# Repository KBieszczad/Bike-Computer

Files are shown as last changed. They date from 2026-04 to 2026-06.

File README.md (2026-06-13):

# Custom IoT Bike Computer

A low-power custom bicycle computer featuring speed measurement, GPS tracking, environmental sensing, and an OLED display. The hardware is designed from scratch with a custom PCB created in KiCad.

## Description

This project aims to build a standalone, power-efficient bike computer. At its core is the Seeed Studio **XIAO nRF52840**, a very energy efficient microcontroller with native Bluetooth Low Energy support.

The device combines data from a classic magnetic reed switch (for precise speed and distance tracking) with an external GPS module for recording traces. Additionally, it integrates a BME280 sensor to monitor environmental conditions (temperature, humidity, and barometric pressure).

### Technical Features
* **Super-Loop Architecture:** Runs on a non-blocking state machine utilizing hardware interrupts (ISR) and atomics for exact speed calculation and UI rendering, completely avoiding `delay()` functions.
* **Persistent Storage (LittleFS):** Automatically saves user settings, wheel circumference, and route history to the internal non-volatile flash memory.
* **GPS Trace Recording:** Caches GPS coordinates in the background while moving and writes directly to flash. Traces can be directly exported over USB Serial to a raw `.gpx` file compatible with for example Strava.
* **Dynamic Power Management:** Implements multiple power modes (Normal, Eco, Ultra Eco). The device sends standard CASIC protocol sleep commands to the GPS module and hardware sleep flags to the BME280 sensor to drastically cut power consumption when full tracking is not needed.

## Hardware Components

* **MCU:** Seeed Studio XIAO nRF52840
* **GPS Module:** ATGM336H
* **Environment Sensor:** BME280
* **Display:** 1.54" I2C OLED (SSD1309)
* **Sensors:** Magnetic Reed Switch (Normally Open)
* **Power:** 470mAh Li-Pol Battery with hardware switch

## Project Structure

```text
.
├── hardware/
│   ├── project.kicad_sch        # KiCad Schematic file
│   ├── project.kicad_pcb        # KiCad PCB layout file
│   └── img/                     # Schematic and PCB layout images
├── software/                    # PlatformIO Firmware files
└── README.md
```

## Visuals

### Schematic
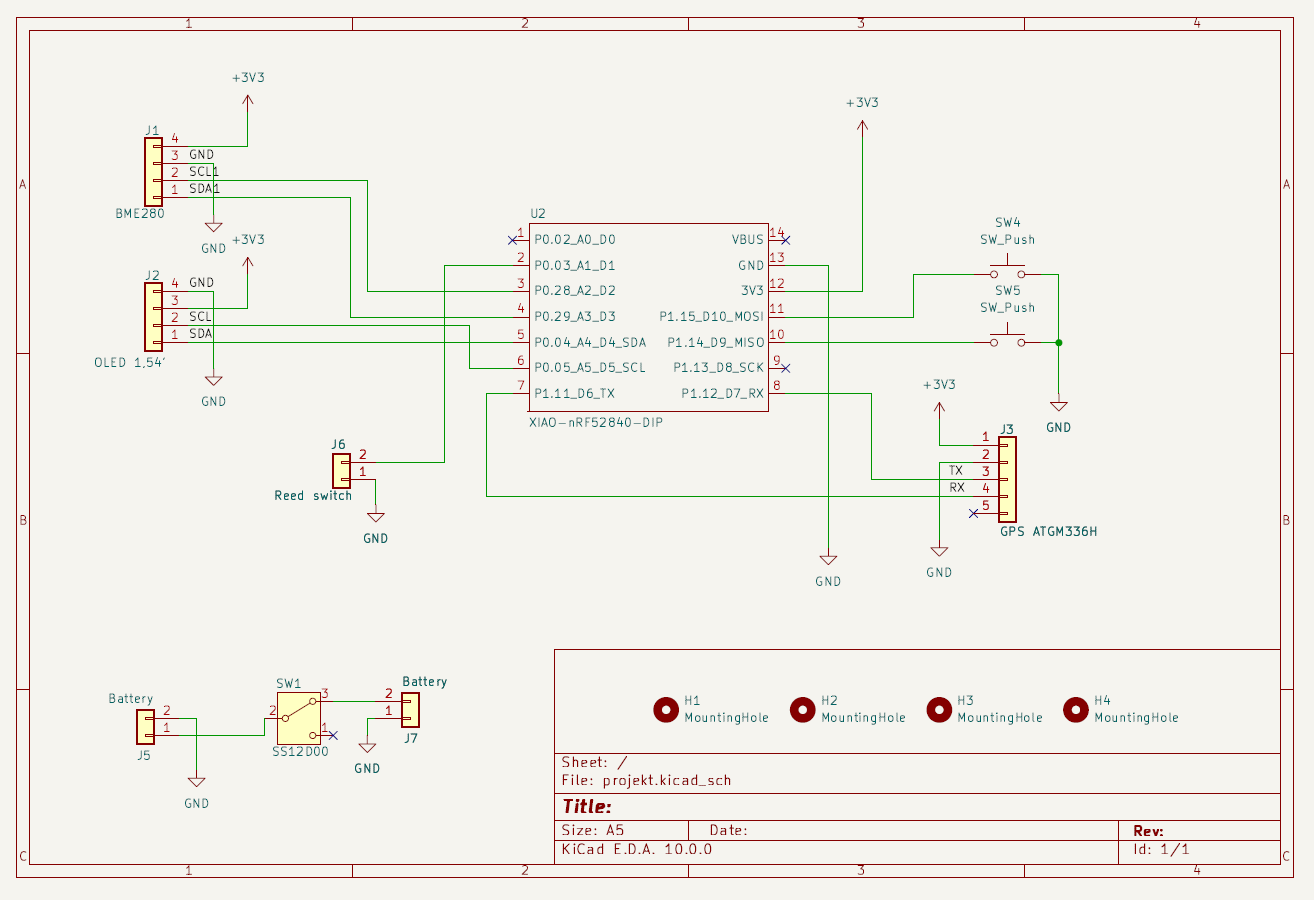
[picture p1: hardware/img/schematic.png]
Schematics


### PCB
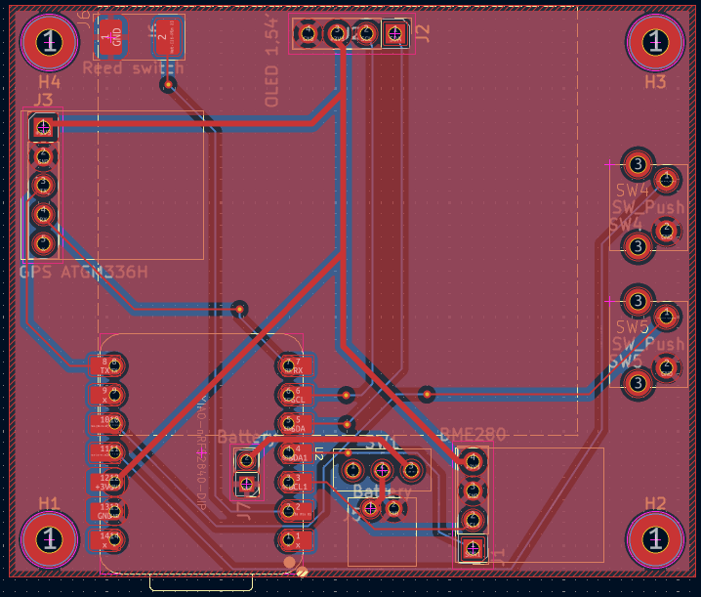
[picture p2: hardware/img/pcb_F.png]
Front

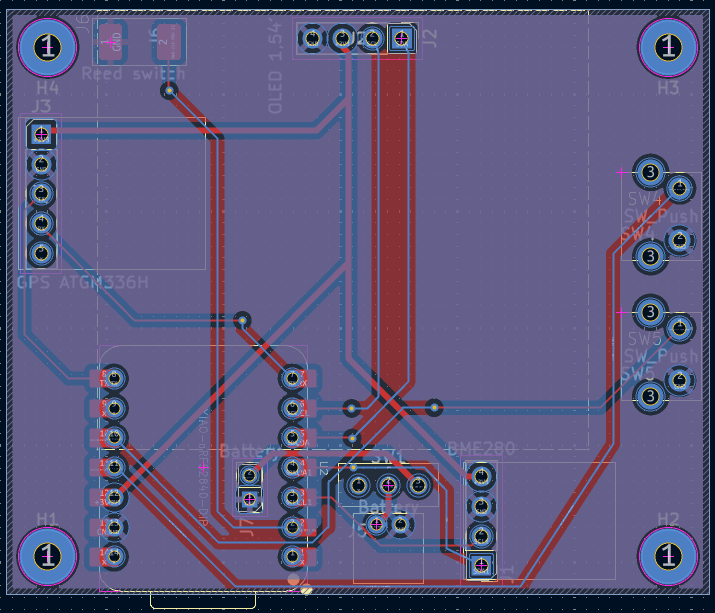
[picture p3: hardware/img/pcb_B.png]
Back


## Installation & Build

### Prerequisites
* **Visual Studio Code** with the **PlatformIO** extension installed.
* Required libraries are automatically managed by `platformio.ini`

### Installing & Flashing
1. **Clone the repository:**
```bash
git clone https://github.com/KBieszczad/Bike-Computer.git
```
2. **Open the `software` folder** in VS Code (PlatformIO).
3. **Connect your XIAO nRF52840** via USB-C.
4. **Build and Upload** the firmware using the PlatformIO build tools.

## Usage & Configuration

1. **Navigation:**
   * **Button 1 (Left):** Short press to cycle through the available screens (Main, Environment, History, GPS, Wheel Setup, Power Mode).
   * **Button 2 (Right):** Used to interact with the current screen (e.g., scroll menus, change settings).
2. **Recording a Trip:**
   * Ensure GPS is toggled `ON` in the GPS Settings screen. The device will automatically start tracking your route once satellites are locked and movement is detected.
   * To finish and save the trip into the device's history, navigate to the **Main Screen**, press and hold **Button 2** for 2 seconds. The trip history will update and distance will reset.
3. **Exporting GPX Track:**
   * Connect the bike computer to a PC via USB.
   * Open a Serial Monitor tool (e.g., in PlatformIO) set to `115200` baud.
   * Navigate to the **GPS SETTINGS** screen on the device, select **EXPORT ROUTE**, and hold Button 2.
   * The device will output raw XML data. Copy this text, save it as a `.gpx` file, and upload it directly to Strava or GPX Studio.

## Authors
Krzysztof Bieszczad
[@KBieszczad](https://github.com/KBieszczad)

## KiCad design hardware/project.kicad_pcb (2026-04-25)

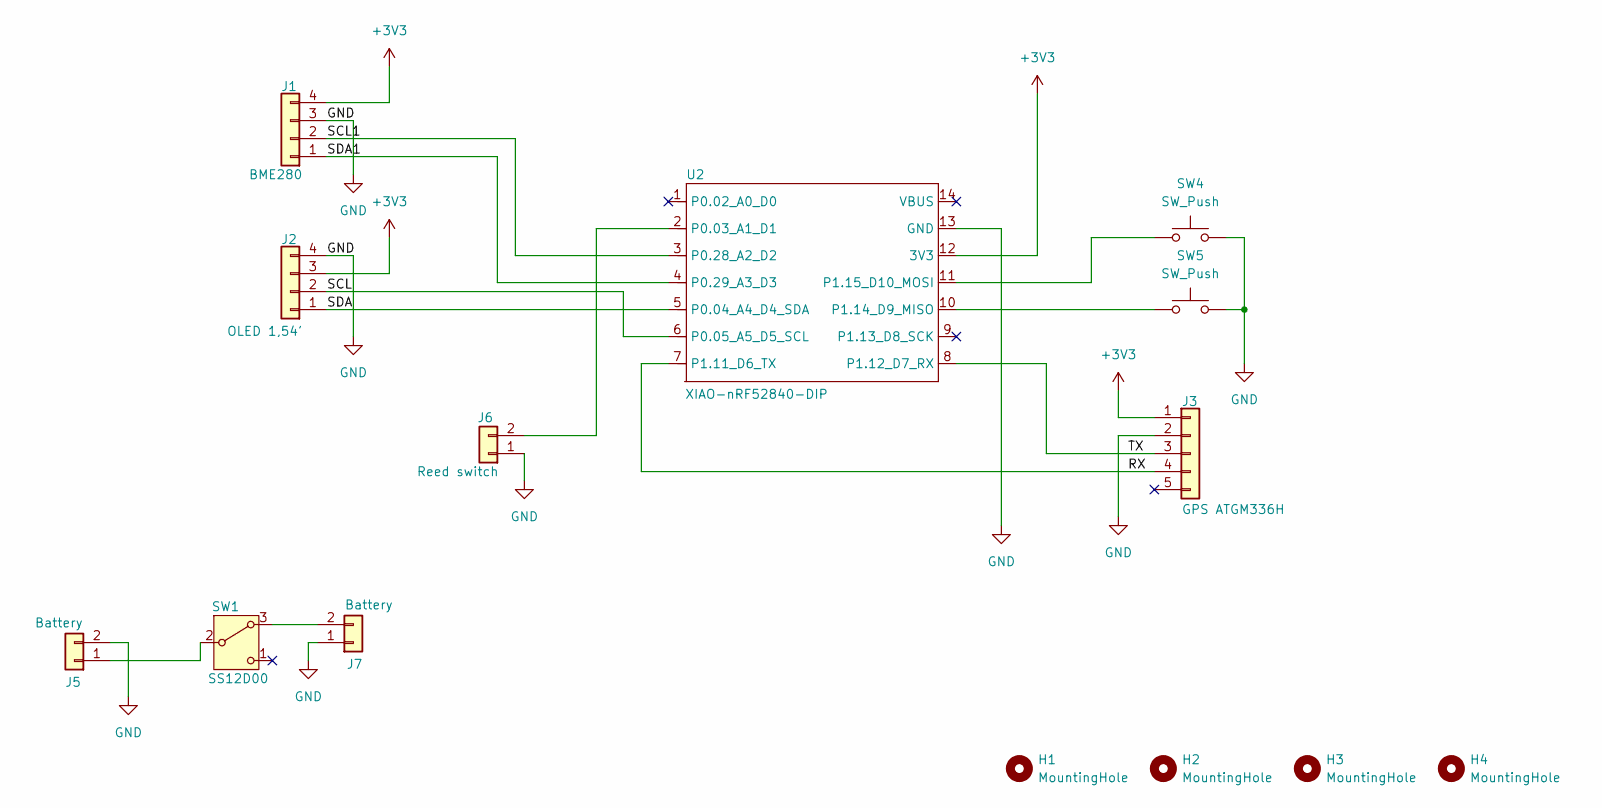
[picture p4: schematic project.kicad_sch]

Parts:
H1, H2, H3, H4: MountingHole; MountingHole_2.2mm_M2_Pad
J1: BME280; PinHeader_1x04_P2.54mm_Vertical
J2: OLED 1,54'; PinHeader_1x04_P2.54mm_Vertical
J3: GPS ATGM336H; PinHeader_1x05_P2.54mm_Vertical
J5: Battery; jst_2mm
J6: Reed switch; reed_switch
J7: Battery; PinHeader_1x02_P2.00mm_Vertical
SW1: SS12D00
SW4, SW5: SW_Push; tact_switch
U2: XIAO-nRF52840-DIP

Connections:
+3V3: J1.4, J2.3, J3.1, U2.12 (3V3)
/RX: J3.4, U2.7 (P1.11_D6_TX)
/SCL: J2.2, U2.6 (P0.05_A5_D5_SCL)
/SCL1: J1.2, U2.3 (P0.28_A2_D2)
/SDA: J2.1, U2.5 (P0.04_A4_D4_SDA)
/SDA1: J1.1, U2.4 (P0.29_A3_D3)
/TX: J3.3, U2.8 (P1.12_D7_RX)
GND: J1.3, J2.4, J3.2, J5.2, J6.1, J7.1, SW4.2, SW5.2, U2.13 (GND)
unnamed: J5.1, SW1.2 (B)
unnamed: J6.2, U2.2 (P0.03_A1_D1)
unnamed: J7.2, SW1.3 (A)
unnamed: SW5.1, U2.10 (P1.14_D9_MISO)
unnamed: SW4.1, U2.11 (P1.15_D10_MOSI)

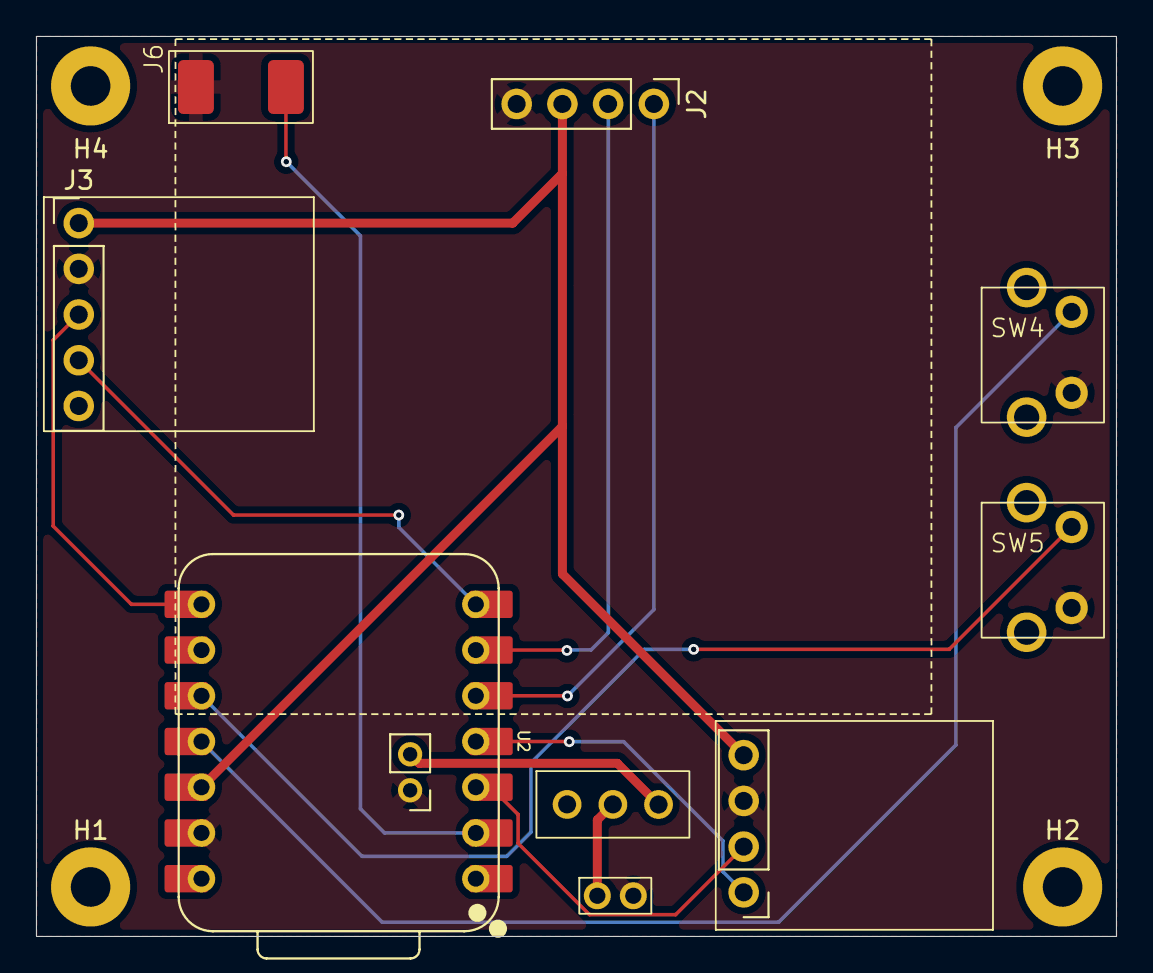
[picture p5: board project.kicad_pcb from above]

Board: 2 copper layers, 60.0 x 50.0 mm, 14 parts (0 on the bottom side), 13 nets.

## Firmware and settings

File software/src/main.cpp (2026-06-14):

#include <Arduino.h>
#include <U8g2lib.h>
#include <Wire.h>
#include <Adafruit_Sensor.h>
#include <Adafruit_BME280.h>
#include <TinyGPSPlus.h>
#include <Bounce2.h>
#include "Globals.h"
#include "Bitmaps.h"

SystemSettings settings = {2155, MODE_NORMAL, true, 0};
Screen currentScreen = SCREEN_MAIN;

volatile float speedKmh = 0.0;
volatile float distanceTripKm = 0.0;
volatile uint32_t tripDurationSec = 0;
float temp = 0.0, hum = 0.0, pres = 0.0;
uint8_t batteryPercent = 100;
bool gpsFix = false;

struct GpsPoint {
  float lat;
  float lon;
  float alt;
  uint16_t year;
  uint8_t month;
  uint8_t day;
  uint8_t hr;
  uint8_t min;
  uint8_t sec;
};
unsigned long lastGpsSaveTime = 0;

U8G2_SSD1309_128X64_NONAME0_F_HW_I2C u8g2(U8G2_R0, U8X8_PIN_NONE);
TinyGPSPlus gps;
Adafruit_BME280 bme; 
TwoWire I2C_BME(NRF_TWIM1, NRF_TWIS1, SPIM1_SPIS1_TWIM1_TWIS1_SPI1_TWI1_IRQn, D3, D2); 

Bounce2::Button btn1 = Bounce2::Button();
Bounce2::Button btn2 = Bounce2::Button();

unsigned long lastDisplayUpdate = 0;
unsigned long lastWeatherUpdate = 0;
volatile unsigned long lastReedPulseTime = 0;
volatile uint8_t pulseAccumulator = 0;
volatile unsigned long isrDt = 0;


int gpsMenuCursor = 0;
int historyCursor = 0;
const uint16_t wheelSizes[] = {2096, 2105, 2136, 2155, 2168, 2180, 2200, 2205, 2235, 2268};
const int NUM_WHEEL_SIZES = sizeof(wheelSizes) / sizeof(wheelSizes[0]);
int wheelSizeCursor = 5;
unsigned long lastSecondTick = 0;

float getSpeed() {
  noInterrupts();
  float v = speedKmh;
  interrupts();
  return v;
}

float getDistance() {
  noInterrupts();
  float d = distanceTripKm;
  interrupts();
  return d;
}

uint32_t getDuration() {
  noInterrupts();
  uint32_t t = tripDurationSec;
  interrupts();
  return t;
}

void resetTrip() {
  noInterrupts();
  distanceTripKm = 0.0;
  tripDurationSec = 0;
  speedKmh = 0.0;
  lastReedPulseTime = millis();
  pulseAccumulator = 0;
  interrupts();
}

void magnetInterrupt() {
  unsigned long currentTime = millis();
  unsigned long dt = currentTime - lastReedPulseTime;
  if (dt > 80) { 
    isrDt = dt;
    pulseAccumulator++;
    lastReedPulseTime = currentTime;
  }
}
#include <InternalFileSystem.h>
#include <Adafruit_LittleFS.h>
using namespace Adafruit_LittleFS_Namespace;

void saveData() {
  InternalFS.remove("/settings.dat");
  auto file = InternalFS.open("/settings.dat", FILE_O_WRITE);
  if (file) {
    file.write((uint8_t*)&settings, sizeof(SystemSettings));
    file.close();
  }
}

void loadData() {
  InternalFS.begin();
  auto file = InternalFS.open("/settings.dat", FILE_O_READ);
  if (file) {
    if (file.size() == sizeof(SystemSettings)) {
      file.read((uint8_t*)&settings, sizeof(SystemSettings));
      file.close();
    } else {
      file.close();
      InternalFS.remove("/settings.dat");
      saveData();
    }
  } else {
    saveData();
  }
  
  for (int i = 0; i < NUM_WHEEL_SIZES; i++) {
    if (wheelSizes[i] == settings.wheelCircumferenceMm) {
      wheelSizeCursor = i;
      break;
    }
  }
}

void switchPowerMode(PowerMode newMode) {
  settings.powerMode = newMode;
  if (newMode == MODE_NORMAL) {
    // bme, gps wake
    bme.setSampling(Adafruit_BME280::MODE_NORMAL, 
                    Adafruit_BME280::SAMPLING_X16, 
                    Adafruit_BME280::SAMPLING_X16, 
                    Adafruit_BME280::SAMPLING_X16, 
                    Adafruit_BME280::FILTER_OFF, 
                    Adafruit_BME280::STANDBY_MS_0_5);
    Serial1.print("\r\n"); 
    settings.gpsEnabled = true;
  } else if (newMode == MODE_ECO) {
    // bme wake, gps sleep
    bme.setSampling(Adafruit_BME280::MODE_NORMAL, 
                    Adafruit_BME280::SAMPLING_X16, 
                    Adafruit_BME280::SAMPLING_X16, 
                    Adafruit_BME280::SAMPLING_X16, 
                    Adafruit_BME280::FILTER_OFF, 
                    Adafruit_BME280::STANDBY_MS_0_5);
    Serial1.print("$PCAS04,2*1A\r\n");
    settings.gpsEnabled = false;
  } else if (newMode == MODE_ULTRA_ECO) {
    // bme, gps sleep
    bme.setSampling(Adafruit_BME280::MODE_SLEEP, 
                    Adafruit_BME280::SAMPLING_X16, 
                    Adafruit_BME280::SAMPLING_X16, 
                    Adafruit_BME280::SAMPLING_X16, 
                    Adafruit_BME280::FILTER_OFF, 
                    Adafruit_BME280::STANDBY_MS_0_5);
    Serial1.print("$PCAS04,2*1A\r\n");
    settings.gpsEnabled = false;
  }
}

void drawMainScreen() {
    u8g2.setFontMode(1);
    u8g2.setBitmapMode(1);
    if (batteryPercent > 80) {
        u8g2.drawXBMP(100, 2, 24, 16, image_battery_100_bits);
    } else if (batteryPercent > 45) {
        u8g2.drawXBMP(100, 2, 24, 16, image_battery_67_bits);
    } else if (batteryPercent > 15) {
        u8g2.drawXBMP(100, 2, 24, 16, image_battery_33_bits);
    } else {
        u8g2.drawXBMP(62, 2, 62, 13, image_battery_10_bits); 
    }

    u8g2.setFont(u8g2_font_profont15_tr);
    u8g2.setCursor(43, 57);
    u8g2.print(getDistance(), 1); u8g2.print(" km");
  
    u8g2.setFont(u8g2_font_profont22_tr);
    u8g2.setCursor(10, 41);
    u8g2.print(getSpeed(), 1); u8g2.print(" km/h");
    
    if (gpsFix) {
        u8g2.drawXBMP(58, 1, 14, 16, image_checked_bits);
    } else {
        u8g2.drawXBMP(58, 1, 11, 16, image_crossed_bits);
    }
    
    u8g2.setFont(u8g2_font_profont15_tr);
    u8g2.setCursor(6, 13);
    u8g2.print((int)temp); u8g2.print(" C");
}

void drawEnvScreen() {
    u8g2.setFontMode(1);
    u8g2.setBitmapMode(1);
    u8g2.setFont(u8g2_font_profont15_tr);
    u8g2.drawStr(3, 16, "Temperature:");
    u8g2.drawStr(4, 35, "Pressure:");
    u8g2.drawStr(4, 54, "Humidity:");
    
    u8g2.setCursor(92, 16); u8g2.print(temp, 1);
    u8g2.setCursor(70, 35); u8g2.print(pres, 0); u8g2.print(" hPa");
    u8g2.setCursor(71, 54); u8g2.print(hum, 0); u8g2.print(" %");
}

void drawHistoryScreen() {
    u8g2.setFontMode(1);
    u8g2.setBitmapMode(1);
    u8g2.setFont(u8g2_font_profont15_tr);
    u8g2.drawStr(29, 13, "LAST ROUTE");
    u8g2.drawStr(6, 29, "Distance:");
    u8g2.drawStr(5, 45, "AVG Speed:");
    u8g2.drawStr(5, 60, "Time:");
    
    if (settings.historyCount > 0) {
      TripRecord &rec = settings.history[historyCursor];
      u8g2.setCursor(80, 29); u8g2.print(rec.distanceKm, 1);
      u8g2.setCursor(80, 45); u8g2.print(rec.speedAvgKmh, 1); 
      
      uint32_t h = rec.durationSec / 3600;
      uint8_t m = (rec.durationSec % 3600) / 60;
      uint8_t s = rec.durationSec % 60;
      char timeBuf[10];
      sprintf(timeBuf, "%02lu:%02u:%02u", (unsigned long)h, m, s);
      u8g2.setCursor(55, 60); u8g2.print(timeBuf); 
      
      u8g2.setCursor(105, 13);
      u8g2.print(historyCursor + 1); u8g2.print("/"); u8g2.print(settings.historyCount);
    } else {
      u8g2.setCursor(80, 45); u8g2.print("---");
    }
}

void drawGpsScreen() {
    u8g2.setFontMode(1);
    u8g2.setBitmapMode(1);
    u8g2.setFont(u8g2_font_profont15_tr);
    u8g2.drawStr(22, 13, "GPS SETTINGS");
    
    const char* options[] = {"GPS: ON", "EXPORT ROUTE", "DELETE ROUTE"};
    if (!settings.gpsEnabled) options[0] = "GPS: OFF";
    
    int startIdx = gpsMenuCursor;
    if (startIdx == 2) startIdx = 1; 
    
    u8g2.setCursor(7, 32);
    if (gpsMenuCursor == startIdx) u8g2.print("> ");
    u8g2.print(options[startIdx]);
    
    u8g2.setCursor(7, 53);
    if (gpsMenuCursor == startIdx + 1) u8g2.print("> ");
    u8g2.print(options[startIdx + 1]);
}

void drawWheelScreen() {
    u8g2.setFontMode(1);
    u8g2.setBitmapMode(1);
    u8g2.setFont(u8g2_font_profont15_tr);
    u8g2.drawStr(33, 13, "SET WHEEL");
    
    u8g2.setFont(u8g2_font_profont22_tr);
    u8g2.setCursor(22, 44);
    u8g2.print(settings.wheelCircumferenceMm); u8g2.print(" mm");
}

void drawPowerScreen() {
    u8g2.setFontMode(1);
    u8g2.setBitmapMode(1);
    u8g2.setFont(u8g2_font_profont15_tr);
    u8g2.drawStr(20, 14, "Power mode");
    
    u8g2.setCursor(24, 42);
    if (settings.powerMode == MODE_NORMAL) u8g2.print("NORMAL");
    else if (settings.powerMode == MODE_ECO) u8g2.print("ECO");
    else u8g2.print("Ultra ECO");
}

void setup() {
  Serial.begin(115200);
  
  analogReadResolution(12); 
  
  u8g2.begin();
  u8g2.setBusClock(400000);
  u8g2.setContrast(100);
  
  I2C_BME.begin();
  bme.begin(0x76, &I2C_BME); 
  
  Serial1.begin(GPS_BAUD); 

  btn1.attach(PIN_BTN1, INPUT_PULLUP);
  btn1.interval(20);
  btn1.setPressedState(LOW);
  
  btn2.attach(PIN_BTN2, INPUT_PULLUP);
  btn2.interval(20);
  btn2.setPressedState(LOW);

  pinMode(PIN_REED, INPUT_PULLUP);
  attachInterrupt(digitalPinToInterrupt(PIN_REED), magnetInterrupt, FALLING);

  loadData();
}

void loop() {
  btn1.update();
  btn2.update();

  noInterrupts();
  uint8_t pulses = pulseAccumulator;
  unsigned long dt = isrDt;
  pulseAccumulator = 0;
  interrupts();
  
  if (pulses > 0) {
    float circM = settings.wheelCircumferenceMm / 1000.0;
    float dtSec = dt / 1000.0; 
    
    noInterrupts();
    speedKmh = (circM / dtSec) * 3.6; 
    distanceTripKm += pulses * (circM / 1000.0); 
    interrupts();
  }

  if (settings.gpsEnabled) {
    while (Serial1.available() > 0) {
      gps.encode(Serial1.read());
    }
    gpsFix = gps.location.isValid() && gps.location.age() < 2000;

    if (gpsFix && gps.date.isValid() && gps.time.isValid()) {
      if (millis() - lastGpsSaveTime > 5000) {
        if (getSpeed() > 2.0) {
          GpsPoint pt;
          pt.lat = gps.location.lat();
          pt.lon = gps.location.lng();
          pt.alt = gps.altitude.meters();
          pt.year = gps.date.year();
          pt.month = gps.date.month();
          pt.day = gps.date.day();
          pt.hr = gps.time.hour();
          pt.min = gps.time.minute();
          pt.sec = gps.time.second();
          
          auto file = InternalFS.open("/trace.dat", FILE_O_WRITE);
          if (file) {
            file.seek(file.size());
            file.write((uint8_t*)&pt, sizeof(GpsPoint));
            file.close();
          }
        }
        lastGpsSaveTime = millis();
      }
    }
  } else {
    gpsFix = false;
  }

  if (btn1.pressed()) {
    if (currentScreen == SCREEN_WHEEL || currentScreen == SCREEN_POWER) {
      saveData();
    }
    currentScreen = (Screen)((currentScreen + 1) % SCREEN_COUNT);
  }

  static bool btn2LongPressHandled = false;
  if (btn2.pressed()) {
    btn2LongPressHandled = false;
  }

  if (currentScreen == SCREEN_MAIN) {
    if (btn2.isPressed() && btn2.currentDuration() > 2000 && !btn2LongPressHandled) {
      float dist = getDistance();
      uint32_t dur = getDuration();
      
      if (dist > 0.1) { 
        for (int i = MAX_HISTORY - 1; i > 0; i--) {
          settings.history[i] = settings.history[i-1];
        }
        settings.history[0].distanceKm = dist;
        settings.history[0].durationSec = dur;
        settings.history[0].speedAvgKmh = (dur > 0) ? (dist / (dur / 3600.0)) : 0;
        if (settings.historyCount < MAX_HISTORY) settings.historyCount++;
        saveData();
      }
      resetTrip();
      btn2LongPressHandled = true; 
    }
  } 
  else if (currentScreen == SCREEN_HISTORY) {
    if (btn2.pressed()) {
      if (settings.historyCount > 0) {
        historyCursor = (historyCursor + 1) % settings.historyCount;
      }
    }
  }
  else if (currentScreen == SCREEN_GPS) {
    if (btn2.released() && btn2.previousDuration() < 1000) {
      gpsMenuCursor = (gpsMenuCursor + 1) % 3;
    }
    if (btn2.isPressed() && btn2.currentDuration() > 1000 && !btn2LongPressHandled) {
      if (gpsMenuCursor == 0) {
        settings.gpsEnabled = !settings.gpsEnabled;
        saveData();
      } else if (gpsMenuCursor == 1) {
        // export route to serial
        auto file = InternalFS.open("/trace.dat", FILE_O_READ);
        if (file) {
          Serial.println("<?xml version=\"1.0\" encoding=\"UTF-8\"?>");
          Serial.println("<gpx version=\"1.1\" creator=\"BikeComputer\">");
          Serial.println("  <trk><name>Bike Route</name><trkseg>");
          GpsPoint pt;
          while (file.read((uint8_t*)&pt, sizeof(GpsPoint)) == sizeof(GpsPoint)) {
            Serial.print("    <trkpt lat=\""); Serial.print(pt.lat, 6);
            Serial.print("\" lon=\""); Serial.print(pt.lon, 6); Serial.println("\">");
            Serial.print("      <ele>"); Serial.print(pt.alt, 1); Serial.println("</ele>");
            char timeBuf[50];
            sprintf(timeBuf, "      <time>%04d-%02d-%02dT%02d:%02d:%02dZ</time>", 
                    pt.year, pt.month, pt.day, pt.hr, pt.min, pt.sec);
            Serial.println(timeBuf);
            Serial.println("    </trkpt>");
          }
          Serial.println("  </trkseg></trk>");
          Serial.println("</gpx>");
          file.close();
        } else {
          Serial.println("No trace saved in memory.");
        }
      } else if (gpsMenuCursor == 2) {
        InternalFS.remove("/trace.dat");
      }
      btn2LongPressHandled = true;
    }
  }
  else if (currentScreen == SCREEN_WHEEL) {
    if (btn2.pressed()) {
      wheelSizeCursor = (wheelSizeCursor + 1) % NUM_WHEEL_SIZES;
      settings.wheelCircumferenceMm = wheelSizes[wheelSizeCursor];
    }
  }
  else if (currentScreen == SCREEN_POWER) {
    if (btn2.pressed()) {
      PowerMode next = (PowerMode)((settings.powerMode + 1) % 3);
      switchPowerMode(next);
    }
  }

  if (millis() - lastReedPulseTime > 3000) {
    speedKmh = 0.0;
  }
  
  if (millis() - lastSecondTick > 1000) {
    if (getSpeed() > 1.0) { 
      noInterrupts();
      tripDurationSec++;
      interrupts();
    }
    lastSecondTick = millis();
  }
  if (millis() - lastWeatherUpdate > 2000 && settings.powerMode != MODE_ULTRA_ECO) {
    temp = bme.readTemperature();
    hum = bme.readHumidity();
    pres = bme.readPressure() / 100.0F;
    
#if defined(PIN_VBAT)
    int vbat_raw = analogRead(PIN_VBAT);
#else
    int vbat_raw = analogRead(A6); 
#endif
    int pct = map(vbat_raw, 1876, 2388, 0, 100);
    batteryPercent = constrain(pct, 0, 100);

    lastWeatherUpdate = millis();
  }

  if (millis() - lastDisplayUpdate > 250) {
    lastDisplayUpdate = millis();
    u8g2.clearBuffer();

    switch (currentScreen) {
      case SCREEN_MAIN: drawMainScreen(); break;
      case SCREEN_ENV: drawEnvScreen(); break;
      case SCREEN_HISTORY: drawHistoryScreen(); break;
      case SCREEN_GPS: drawGpsScreen(); break;
      case SCREEN_WHEEL: drawWheelScreen(); break;
      case SCREEN_POWER: drawPowerScreen(); break;
      default: break;
    }
    
    u8g2.sendBuffer();
  }
}

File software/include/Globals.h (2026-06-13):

#pragma once

#include <Arduino.h>

#define PIN_REED D1   
#define PIN_BTN1 D10   
#define PIN_BTN2 D9  

#define GPS_BAUD 9600

enum Screen {
  SCREEN_MAIN = 0,
  SCREEN_ENV,
  SCREEN_HISTORY,
  SCREEN_GPS,
  SCREEN_WHEEL,
  SCREEN_POWER,
  SCREEN_COUNT
};

enum PowerMode {
  MODE_NORMAL = 0,
  MODE_ECO,
  MODE_ULTRA_ECO
};

struct TripRecord {
  float distanceKm;
  float speedAvgKmh;
  uint32_t durationSec;
};

#define MAX_HISTORY 5

struct SystemSettings {
  uint16_t wheelCircumferenceMm;
  PowerMode powerMode;
  bool gpsEnabled;
  uint8_t padding; 
  TripRecord history[MAX_HISTORY];
  uint8_t historyCount;
};

extern SystemSettings settings;
extern Screen currentScreen;

extern volatile float speedKmh;
extern volatile float distanceTripKm;
extern float temp, hum, pres;
extern uint8_t batteryPercent;
extern bool gpsFix;

#include <U8g2lib.h>
#include <TinyGPSPlus.h>
extern U8G2_SSD1309_128X64_NONAME0_F_HW_I2C u8g2;
extern TinyGPSPlus gps;

void saveData();
void loadData();
void switchPowerMode(PowerMode newMode);

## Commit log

2026-05-16 add gerber files
2026-05-21 breadboard testing/prototype code
2026-05-21 add pcb layout images
2026-06-06 feat: power modes, save gps to file
2026-06-13 update files
    [project.kicad_pcb, project.kicad_sch]
2026-06-14 style: font, wheel sizes
